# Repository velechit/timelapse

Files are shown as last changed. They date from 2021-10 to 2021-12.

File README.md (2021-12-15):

# Timelapse Timer

Photography Timer based on Atmega8 controller,  OLED display and button controls.

## Specialities:

* USB Based boot loader (based on [baerwolf](https://github.com/baerwolf/USBaspLoader)'s code)
* Minimalsitic SSD1306 driver
* SoftSwitch power on

This project contains Circuit Schematic, PCB Layout, bootloader (Customized), Main Application

This project demonstrates using linker scripts to place code bases at specific location and re-using them across different codes
* Bootloader also implements a minimalistic SSD1306 driver. As the bootloader space in ATMEGA8 is limited to 2k (start address `0x1800`), the driver is placed at `0x1600` which can be accessed through absolute addressing
* The application program (the actual timelapse code) makes use of this SSD1306 driver through absolute addressing
## Progress so far

- [x] Bootloader
- [x] SSD1306 Driver
- [x] Integrate SSD1306 Driver with bootloader, and display a USB icon when in boot load mode
- [x] Update Makefile for bootloader to generate liner script for display driver entry points to be accessed by application program
- [x] Design the PCB
- [x] Get PCB Fabricated
- [x] Framework for the application
- [ ] Main application program

<br/>

**UPDATE 1: Added power off code in bootloader**

**UPDATE 2: Initial dummy firmware implemented which is simple counter**

**UPDATE 3: got the fabricated PCB, assembled, and uploaded the bootloader & the dummy firmware... till now all working**

**UPDATE 4: Framework for main application ready**

<br/>

 _I thought of fabricating the board myself. Due to insufficient time, I have ordered from online fab. I had two options for shipment either too expencive and fast delivery or too slow with easy on pockets. I have chosen the latter, waiting for the board to arrive_

**IMPORTANT Update : I found a issue with the power on circuitory that the internal IO driver transistor is too leakey and is permanently turning on the PMOS power gate. Hence I have added additional NMOS (`2n7002`) to ground externally**

## Toolchain needed
The bootloader and firmware are developed using barebone `avr-gcc` and `avr-libc`

Install `avr-gcc` and `avr-libc`. Under Windows you may chose to use [WinAVR](http://winavr.sourceforge.net/).

Under linux (`Ubuntu` epsecially)
> `sudo apt install gcc-avr avr-libc`

You will also need gmake (generally part of the installation). If not, install using
> `sudo apt install make`

Compile using `make`

### Fuse Settings
The board is designed with external oscillator module. Hence the below fuse settings are used for `Atmega8`

```
lfuse: 1 1 0 0 0 0 0 0 = 0xC0
       | | | | | | | |
       | | | | | | | +- CKSEL0   - External Clock
       | | | | | | +--- CKSEL1
       | | | | | +----- CKSEL2
       | | | | +------- CKSEL3
       | | | +--------- SUT0     - Startup Time 0ms
       | | +----------- SUT1
       | +------------- BODEN    - Brown-out detection disabled
       +--------------- BODLEVEL - Brown-out detection level (N/A)

hfuse: 1 1 0 0 1 0 0 0 = 0xC8
       | | | | | | | |
       | | | | | | | +- BOOTRST  - Reset boots to boot loader
       | | | | | | +--- BOOTSZ0  - Boot section size 2k
       | | | | | +----- BOOTSZ1
       | | | | +------- EESAVE   - No EEPROM save on program
       | | | +--------- CKOPT    - Full Swing Clock
       | | +----------- SPIEN    - Serial programming enabled
       | +------------- WTDON    - Watchdog Timer disabled
       +--------------- RSTDISBL - Reset not disabled
```
Program the above fuses using:

> `avrdude -p atmega8 -P usb -c usbasp -U lfuse:w:0xC0:m -U hfuse:w:0xC8:m`

## Uploading the bootloader
The bootloader and the fuse settings have to be uploaded using any other method of loading (Using Arduino as ISP or USBAsp programmer). Once programmed, the controller can be soldered to the application board and the programmed bootloader be used to upload the main firmware.

## 3D models
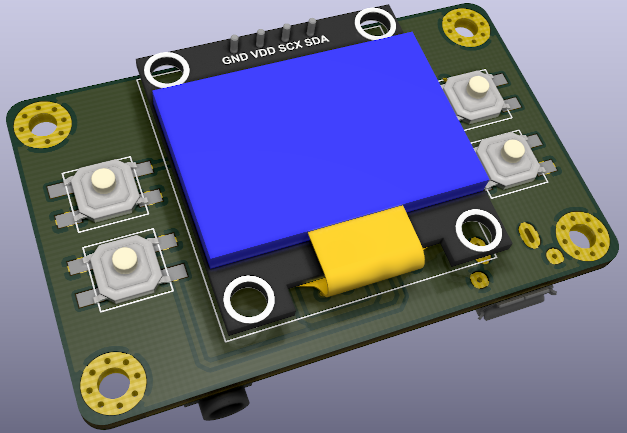
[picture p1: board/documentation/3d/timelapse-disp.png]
Board Side

<br/>
*3D Model of display side of the board*

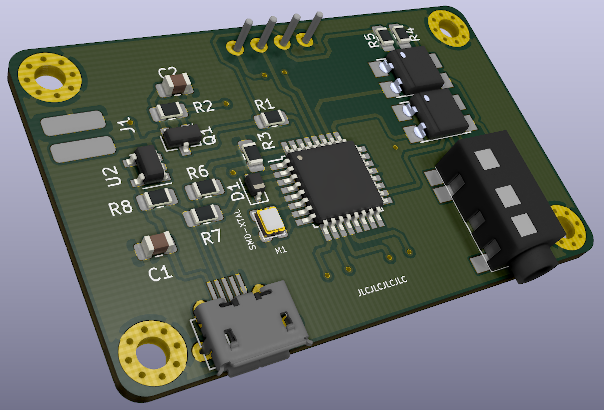
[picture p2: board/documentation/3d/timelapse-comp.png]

<br/>
*3D Model of component side of the board*

## Post Fabrication
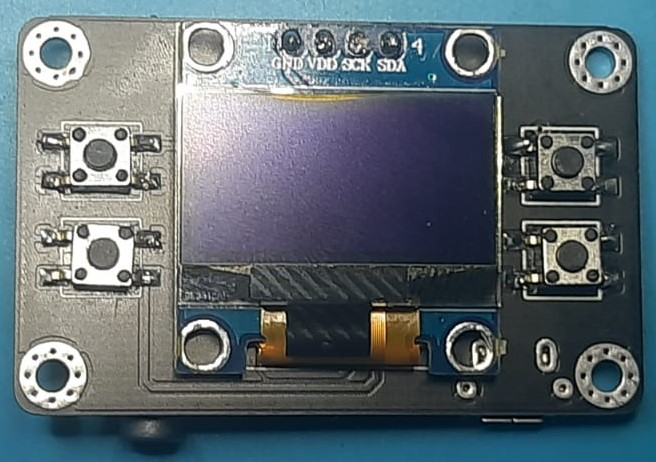
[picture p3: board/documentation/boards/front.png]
Board Side

<br/>
*Display side of the board*

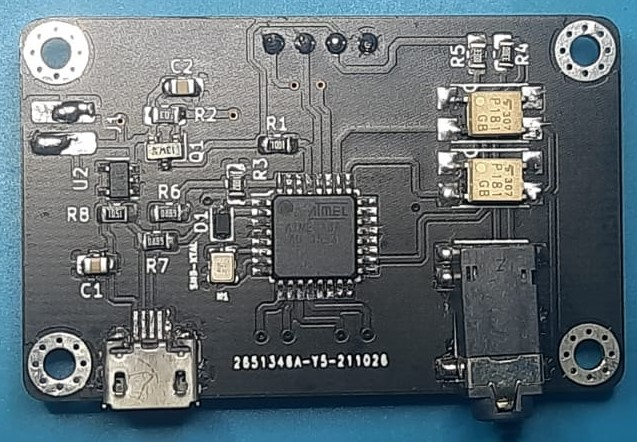
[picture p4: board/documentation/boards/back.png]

<br/>
*Component side of the board*

Full documentation can be found [here](https://raw.githack.com/velechit/timelapse/main/board/documentation/index.html)

PCB is designed using 

(https://www.kicad.org)

Download KiCad project files [here](board/timelapse.zip?raw=true)

Schematic can be found [here](board/schematic.pdf?raw=true)

email: elechi@gmail.com

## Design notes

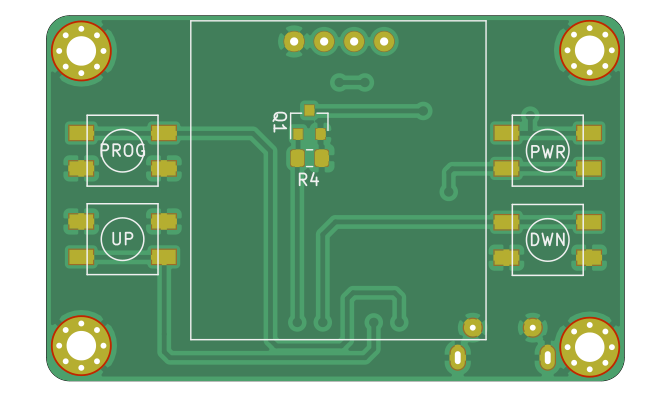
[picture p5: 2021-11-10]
board/documentation/boards/timelapse-back.png

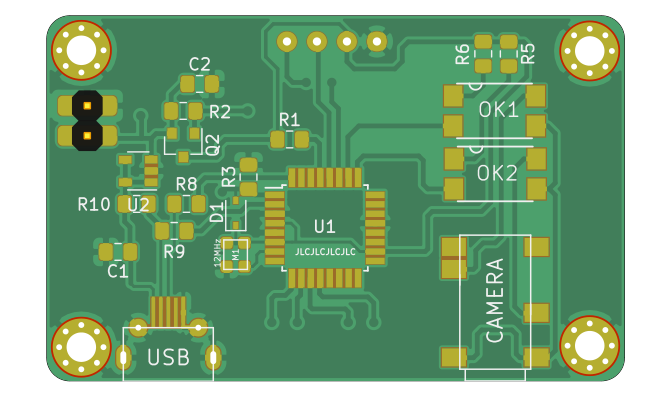
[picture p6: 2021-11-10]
board/documentation/boards/timelapse-front.png

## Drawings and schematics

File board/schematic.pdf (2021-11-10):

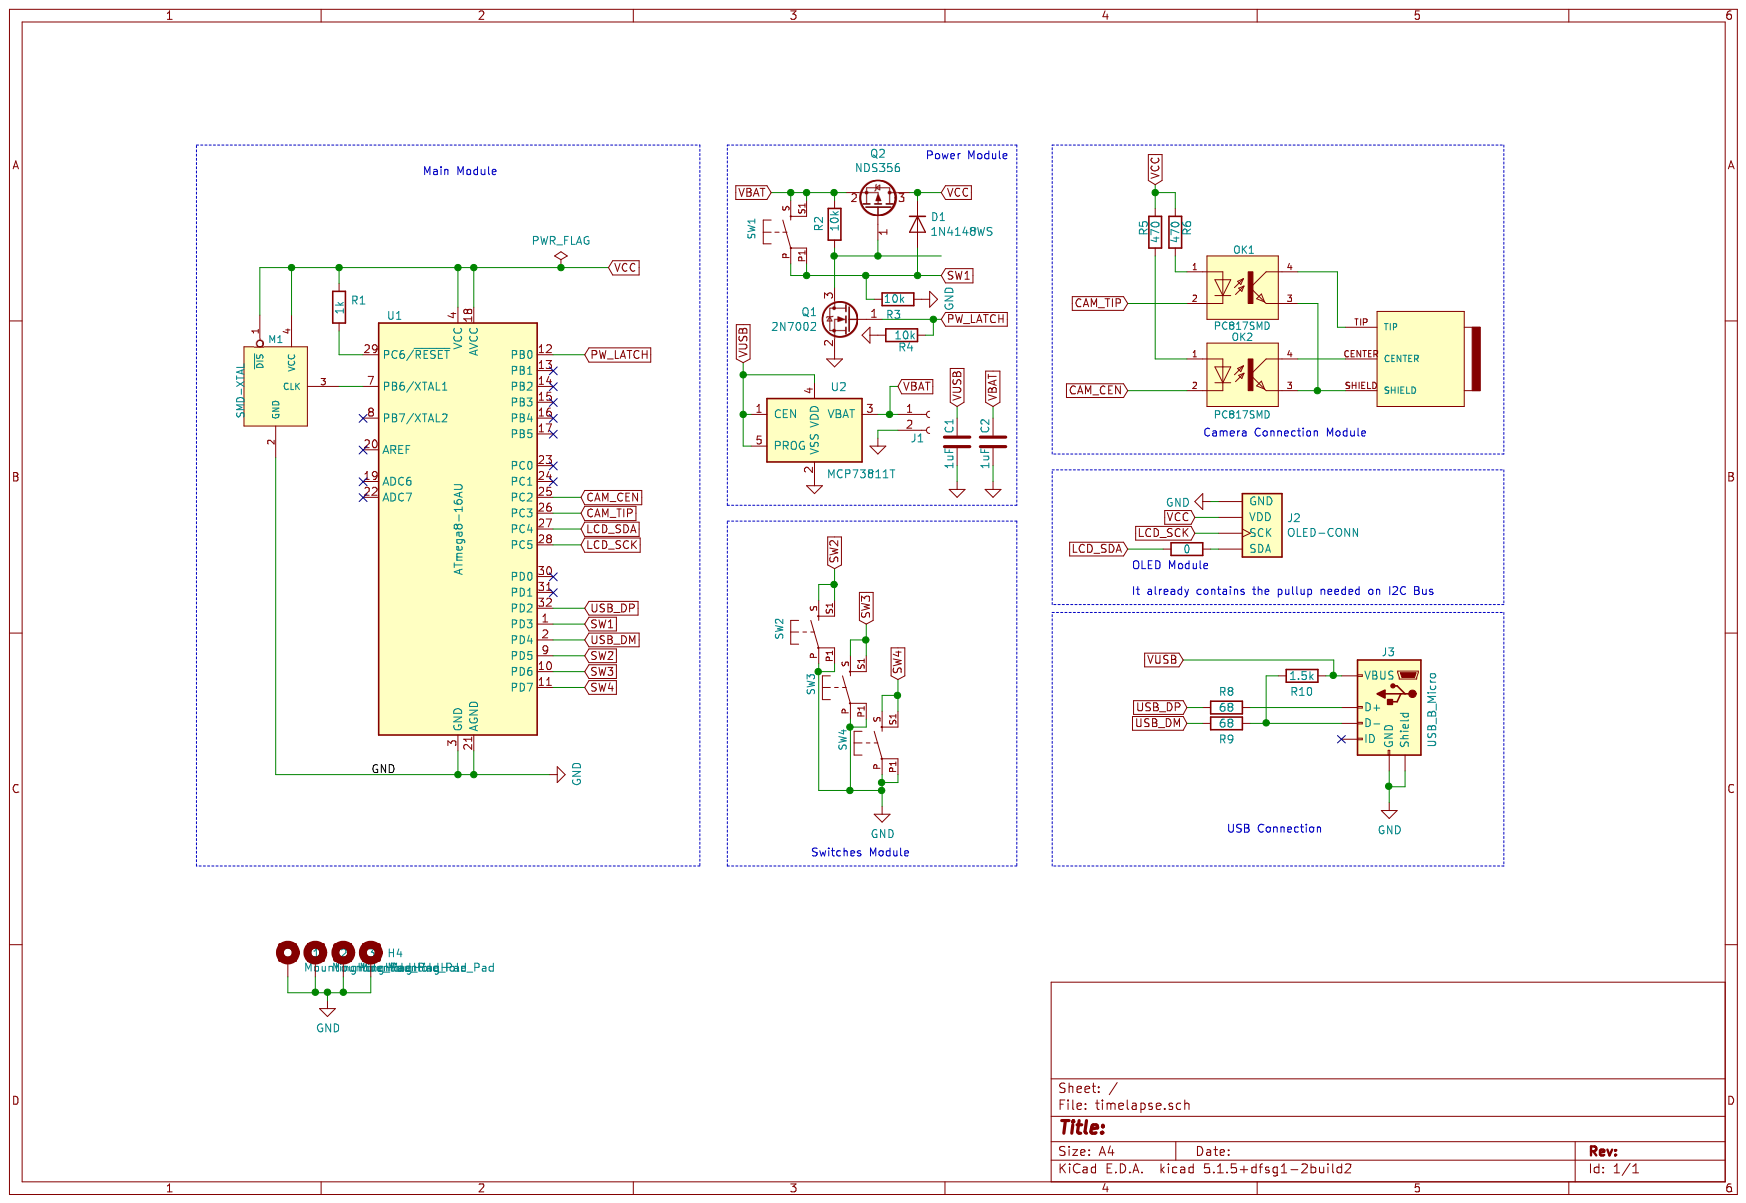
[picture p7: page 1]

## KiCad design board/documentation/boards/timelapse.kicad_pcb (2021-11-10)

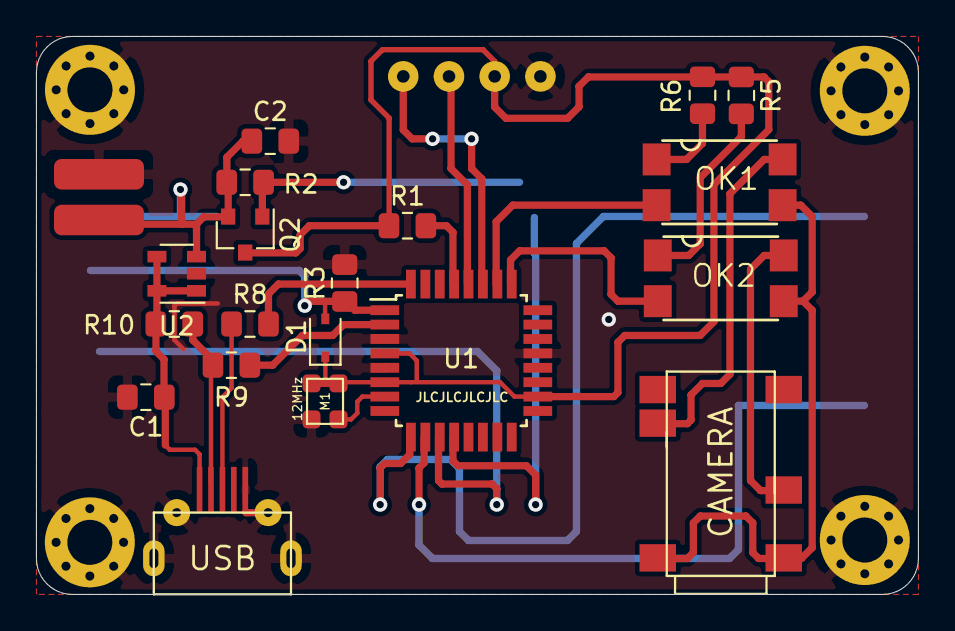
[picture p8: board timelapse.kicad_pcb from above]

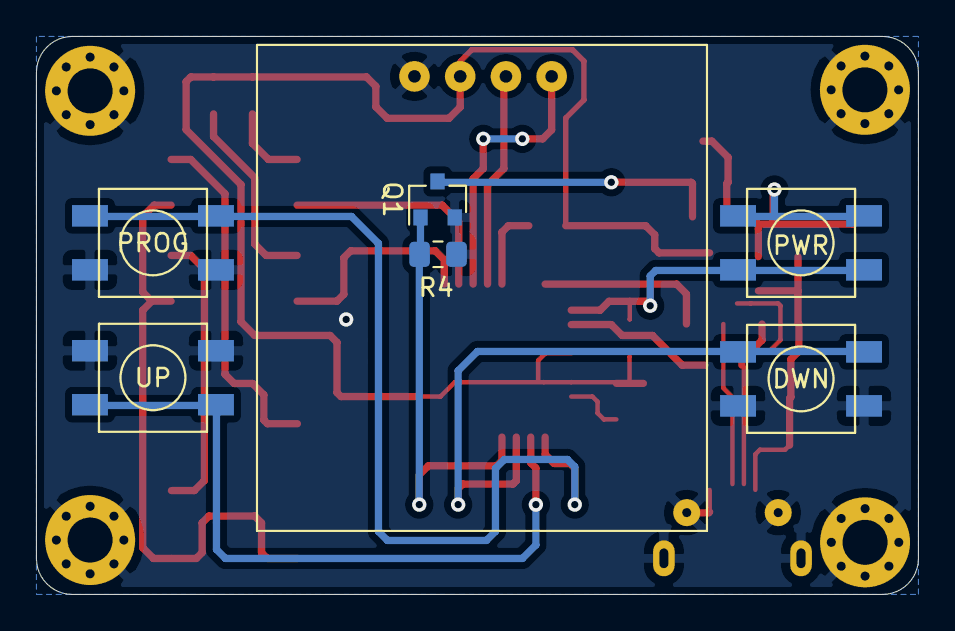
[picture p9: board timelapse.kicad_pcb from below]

Board: 2 copper layers, 49.0 x 31.0 mm, 31 parts (7 on the bottom side), 24 nets.

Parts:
C1, C2: 1uF; C_0805_2012Metric_Pad1.15x1.40mm_HandSolder
D1: 1N4148WS; D_SOD-323
H1, H2, H3, H4: MountingHole_Pad; MountingHole_2.5mm_Pad_Via
J1: Battery; PinHeader_1x02_P2.54mm_Vertical
J2: OLED-CONN; OLED-Display-0.96
J3: USB; MICROUSB-V8
M1: 12MHz; SMDXTAL
M2: CAMERA; CAM-CONN-NOKIA
OK1, OK2: PC817SMD; SMD4
Q1: 2N7002; SOT-23
Q2: NDS356; SOT-23
R1: 1k; R_0805_2012Metric_Pad1.15x1.40mm_HandSolder
R2, R3, R4: 10k; R_0805_2012Metric_Pad1.15x1.40mm_HandSolder
R5, R6: 470; R_0805_2012Metric_Pad1.15x1.40mm_HandSolder
R8, R9: 68; R_0805_2012Metric_Pad1.15x1.40mm_HandSolder
R10: 1.5k; R_0805_2012Metric_Pad1.15x1.40mm_HandSolder
SW1: PWR; 4PIN-S
SW2: PROG; 4PIN-S
SW3: UP; 4PIN-S
SW4: DWN; 4PIN-S
U1: ATmega8-16AU; TQFP-32_7x7mm_P0.8mm
U2: MCP73811T; SOT-23-5

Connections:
CAM_CEN: OK2.2, U1.25
CAM_TIP: OK1.2, U1.26
GND: C1.2, C2.2, H1.1, H2.1, H3.1, H4.1, J1.2, J2.1, J3.GND, J3.SHIELD, M1.2, Q1.2, R3.2, R4.2, SW2.P, SW2.P1, SW3.P, SW3.P1, SW4.P, SW4.P1, U1.3, U1.5, U1.21, U2.2
LCD_SCK: J2.3, U1.28
unnamed: J3.D+, R8.1
unnamed: J3.D-, R9.1, R10.2
unnamed: M1.3, U1.7
unnamed: M2.CENTER, OK2.4
unnamed: M2.SHIELD, OK1.3, OK2.3
unnamed: M2.TIP, OK1.4
unnamed: OK1.1, R6.2
unnamed: OK2.1, R5.2
unnamed: Q1.3, Q2.1, R2.2
unnamed: R1.2, U1.29
PW_LATCH: Q1.1, R4.1, U1.12
SW1: D1.2, R3.1, SW1.P, SW1.P1, U1.1
SW2: SW2.S, SW2.S1, U1.9
SW3: SW3.S, SW3.S1, U1.10
SW4: SW4.S, SW4.S1, U1.11
USB_DM: R9.2, U1.2
USB_DP: R8.2, U1.32
VBAT: C2.1, J1.1, Q2.2, R2.1, SW1.S, SW1.S1, U2.3
VCC: D1.1, J2.2, M1.1, M1.4, Q2.3, R1.1, R5.1, R6.1, U1.4, U1.6, U1.18
VUSB: C1.1, J3.VBUS, R10.1, U2.1, U2.4, U2.5

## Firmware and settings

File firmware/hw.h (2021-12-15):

#ifndef __HARDWARE_H__
#define __HARDWARE_H__

#define KEYPAD_DIR_PORT DDRD
#define KEYPAD_PORT     PIND
#define KEYPAD_PORT_OUT PORTD
#define KEYPAD_BTN1_BIT 3  // PWR
#define KEYPAD_BTN2_BIT 5  // PROG
#define KEYPAD_BTN3_BIT 6  // UP
#define KEYPAD_BTN4_BIT 7  // DOWN
#define KEYPAD_PWR_BIT  KEYPAD_BTN1_BIT

#define CAMERA_DIR_PORT   DDRC
#define CAMERA_PORT       PORTC
#define CAMERA_1_BIT      2
#define CAMERA_2_BIT      3

#define POWER_LATCH_DIR_PORT  DDRB
#define POWER_LATCH_PORT      PORTB
#define POWER_LATCH_BIT       0

#endif /* ! __HARDWARE_H__ */

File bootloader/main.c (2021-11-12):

/* Name: main.c
 * Project: USBaspLoader
 * Author: Christian Starkjohann
 * Author: Stephan Baerwolf
 * Creation Date: 2007-12-08
 * Modification Date: 2013-03-31
 * Tabsize: 4
 * Copyright: (c) 2007 by OBJECTIVE DEVELOPMENT Software GmbH
 * License: GNU GPL v2 (see License.txt)
 */

#include "spminterface.h"  /* must be included as first! */

#include <avr/io.h>
#include <avr/interrupt.h>
#include <avr/pgmspace.h>
#include <avr/wdt.h>
#include <avr/boot.h>
#include <avr/eeprom.h>
#include <util/delay.h>

#include "SSD1306.h"

#if 0
/*
 * 29.09.2012 /  30.09.2012
 * 
 * Since cpufunc.h is not needed in this context and
 * since it is not available in all toolchains, this include
 * becomes deactivated by github issue-report.
 * (In case of trouble it remains in sourcecode for reactivation.)
 * 
 * The autor would like to thank Lena-M for reporting this
 * issue (https://github.com/baerwolf/USBaspLoader/issues/1).
 */
#include <avr/cpufunc.h>
#endif

#include <avr/boot.h>

#include <string.h>



#include "bootloaderconfig.h"

#include "usbdrv/usbdrv.c"
static usbMsgLen_t usbFunctionDescriptor(struct usbRequest *rq) {
  return 0;
}

#ifndef BOOTLOADER_ADDRESS
  #error need to know the bootloaders flash address!
#endif
#define BOOTLOADER_PAGEADDR	(BOOTLOADER_ADDRESS - (BOOTLOADER_ADDRESS % SPM_PAGESIZE))

/* ------------------------------------------------------------------------ */

/* Request constants used by USBasp */
#define USBASP_FUNC_CONNECT         1
#define USBASP_FUNC_DISCONNECT      2
#define USBASP_FUNC_TRANSMIT        3
#define USBASP_FUNC_READFLASH       4
#define USBASP_FUNC_ENABLEPROG      5
#define USBASP_FUNC_WRITEFLASH      6
#define USBASP_FUNC_READEEPROM      7
#define USBASP_FUNC_WRITEEEPROM     8
#define USBASP_FUNC_SETLONGADDRESS  9

// additional USBasp Commands
#define USBASP_FUNC_SETISPSCK	     10
#define USBASP_FUNC_TPI_CONNECT      11
#define USBASP_FUNC_TPI_DISCONNECT   12
#define USBASP_FUNC_TPI_RAWREAD      13
#define USBASP_FUNC_TPI_RAWWRITE     14
#define USBASP_FUNC_TPI_READBLOCK    15
#define USBASP_FUNC_TPI_WRITEBLOCK   16
#define USBASP_FUNC_GETCAPABILITIES 127
/* ------------------------------------------------------------------------ */

#ifndef ulong
#   define ulong    unsigned long
#endif
#ifndef uint
#   define uint     unsigned int
#endif


/* allow compatibility with avrusbboot's bootloaderconfig.h: */
#ifdef BOOTLOADER_INIT
#   define bootLoaderInit()         BOOTLOADER_INIT
#   define bootLoaderExit()
#endif
#ifdef BOOTLOADER_CONDITION
#   define bootLoaderCondition()    BOOTLOADER_CONDITION
#endif

/* device compatibility: */
#ifndef GICR    /* ATMega*8 don't have GICR, use MCUCR instead */
#   define GICR     MCUCR
#endif

/* ------------------------------------------------------------------------ */

#if (FLASHEND) > 0xffff /* we need long addressing */
#   define CURRENT_ADDRESS  currentAddress.l
#   define addr_t           ulong
#else
#   define CURRENT_ADDRESS  currentAddress.w[0]
#   define addr_t           uint
#endif

typedef union longConverter{
    addr_t  l;
    uint    w[sizeof(addr_t)/2];
    uchar   b[sizeof(addr_t)];
}longConverter_t;


#define __IMPLEMENT_PRESERVE_WATCHDOG	((PRESERVE_WATCHDOG) && (!(USE_EXCESSIVE_ASSEMBLER)) && ((NEED_WATCHDOG) || (defined(__MCUCSR_COMPATMODE))))
#if (__IMPLEMENT_PRESERVE_WATCHDOG)
static uint8_t __original_WDTCR;
#endif

#if (BOOTLOADER_CAN_EXIT)
#	if (BOOTLOADER_LOOPCYCLES_TIMEOUT)
#		if (BOOTLOADER_LOOPCYCLES_TIMEOUT < 256)
#			if ((HAVE_UNPRECISEWAIT))
	 register uint8_t timeout_remaining __asm__("r2");
#			else
static volatile uint8_t timeout_remaining;
#			endif
#		else
static volatile uint16_t timeout_remaining;
#		endif
#	endif

#	define stayinloader_initialValue 0xfe
#	if ((HAVE_UNPRECISEWAIT))
/* here we have to assume we need to optimize for every byte */
	 register uint8_t stayinloader __asm__("r17");
#	else
static volatile uint8_t stayinloader;
#	endif
#endif

static longConverter_t  	currentAddress; /* in bytes */
static uchar            	bytesRemaining;
static uchar            	isLastPage;
#if HAVE_EEPROM_PAGED_ACCESS
static uchar            	currentRequest;
#else
static const uchar      	currentRequest = 0;
#endif

static const uchar  signatureBytes[4] = {
#ifdef SIGNATURE_BYTES
    SIGNATURE_BYTES
#elif defined (__AVR_ATmega8535__)
    0x1e, 0x93, 0x08, 0
#elif defined (__AVR_ATmega8__) || defined (__AVR_ATmega8A__) || defined (__AVR_ATmega8HVA__)
    0x1e, 0x93, 0x07, 0
#elif defined (__AVR_ATmega16__)
    0x1e, 0x94, 0x03, 0
#elif defined (__AVR_ATmega32__)
    0x1e, 0x95, 0x02, 0
#elif defined (__AVR_ATmega48__) || defined (__AVR_ATmega48A__)
    #error ATmega48 does not support bootloaders!
    0x1e, 0x92, 0x05, 0
#elif defined (__AVR_ATmega48PA__) || defined (__AVR_ATmega48P__)
    #error ATmega48P does not support bootloaders!
    0x1e, 0x92, 0x0A, 0
#elif defined (__AVR_ATmega88__) || defined (__AVR_ATmega88A__)
    0x1e, 0x93, 0x0a, 0
#elif defined (__AVR_ATmega88PA__) || defined (__AVR_ATmega88P__)
    0x1e, 0x93, 0x0F, 0
#elif defined (__AVR_ATmega162__)
    0x1e, 0x94, 0x04, 0
#elif defined (__AVR_ATmega164A__)
    0x1e, 0x94, 0x0f, 0
#elif defined (__AVR_ATmega164P__) || defined (__AVR_ATmega164PA__)
    0x1e, 0x94, 0x0a, 0
#elif defined (__AVR_ATmega168__) || defined (__AVR_ATmega168A__)
    0x1e, 0x94, 0x06, 0
#elif defined (__AVR_ATmega168PA__) || defined (__AVR_ATmega168P__)
    0x1e, 0x94, 0x0B, 0
#elif defined (__AVR_ATmega324A__)
    0x1e, 0x95, 0x15, 0
#elif defined (__AVR_ATmega324P__)
    0x1e, 0x95, 0x08, 0
#elif defined (__AVR_ATmega324PA__)
    0x1e, 0x95, 0x11, 0
#elif defined (__AVR_ATmega328__)
    0x1e, 0x95, 0x14, 0
#elif defined (__AVR_ATmega328P__)
    0x1e, 0x95, 0x0f, 0
#elif defined (__AVR_ATmega640__)
    0x1e, 0x96, 0x08, 0
#elif defined (__AVR_ATmega644__) || defined (__AVR_ATmega644A__)
    0x1e, 0x96, 0x09, 0
#elif defined (__AVR_ATmega644P__) || defined (__AVR_ATmega644PA__)
    0x1e, 0x96, 0x0a, 0
#elif defined (__AVR_ATmega128__)
    0x1e, 0x97, 0x02, 0
#elif defined (__AVR_ATmega1280__)
    0x1e, 0x97, 0x03, 0
#elif defined (__AVR_ATmega1281__)
    0x1e, 0x97, 0x04, 0
#elif defined (__AVR_ATmega1284__)
    0x1e, 0x97, 0x06, 0
#elif defined (__AVR_ATmega1284P__)
    0x1e, 0x97, 0x05, 0
#elif defined (__AVR_ATmega2560__)
    0x1e, 0x98, 0x01, 0
#elif defined (__AVR_ATmega2561__)
    0x1e, 0x98, 0x02, 0
#else
#   if (defined(SIGNATURE_0) && defined(SIGNATURE_1) && defined(SIGNATURE_2))
#     warning "Device signature is not known - using AVR Libc suggestion..."
    SIGNATURE_0, SIGNATURE_1, SIGNATURE_2, 0
#   else
#     error "Device signature is not known, please edit main.c!"
#   endif
#endif
};

/* ------------------------------------------------------------------------ */

#if (HAVE_BOOTLOADERENTRY_FROMSOFTWARE)
void __attribute__ ((section(".init3"),naked,used,no_instrument_function)) __BOOTLOADERENTRY_FROMSOFTWARE__bootup_investigate_RAMEND(void);
void __BOOTLOADERENTRY_FROMSOFTWARE__bootup_investigate_RAMEND(void) {
  asm volatile (
    "in		%[mcucsrval]	,	%[mcucsrio]\n\t"
    "ldi	r29		,	%[ramendhi]\n\t"
    "ldi	r28		,	%[ramendlo]\n\t"
#if (FLASHEND>131071)
    "ld		%[result]	,	Y+\n\t"
    "cpi	%[result]	,	%[bootaddrhi]\n\t"
    "brne	__BOOTLOADERENTRY_FROMSOFTWARE__bootup_investigate_RAMEND_mismatch%=\n\t"
#endif
    "ld		%[result]	,	Y+\n\t"
    "cpi	%[result]	,	%[bootaddrme]\n\t"
    "ld		%[result]	,	Y+\n\t"
    "breq	__BOOTLOADERENTRY_FROMSOFTWARE__bootup_investigate_RAMEND_done%=\n\t"

    "__BOOTLOADERENTRY_FROMSOFTWARE__bootup_investigate_RAMEND_mismatch%=:\n\t"
    "ldi	%[result]	,	0xff\n\t"

    "__BOOTLOADERENTRY_FROMSOFTWARE__bootup_investigate_RAMEND_done%=:\n\t"
    : [result]		"=a" (__BOOTLOADERENTRY_FROMSOFTWARE__bootup_RAMEND_doesmatch),
      [mcucsrval]	"=a" (__BOOTLOADERENTRY_FROMSOFTWARE__bootup_MCUCSR)
    : [mcucsrio]	"I"  (_SFR_IO_ADDR(MCUCSR)),
#if (FLASHEND>131071)
      [ramendhi]	"M" (((RAMEND - 2) >> 8) & 0xff),
      [ramendlo]	"M" (((RAMEND - 2) >> 0) & 0xff),
      [bootaddrhi]	"M" (((__BOOTLOADERENTRY_FROMSOFTWARE__EXPECTEDADDRESS) >>16) & 0xff),
#else
      [ramendhi]	"M" (((RAMEND - 1) >> 8) & 0xff),
      [ramendlo]	"M" (((RAMEND - 1) >> 0) & 0xff),
#endif
      [bootaddrme]	"M" (((__BOOTLOADERENTRY_FROMSOFTWARE__EXPECTEDADDRESS) >> 8) & 0xff)
    
  );
}
#endif

#if (USE_BOOTUP_CLEARRAM)
/*
* Under normal circumstances, RESET will not clear contents of RAM.
* As always, if you want it done - do it yourself...
*/
void __attribute__ ((section(".init3"),naked,used,no_instrument_function)) __func_clearram(void);
void __func_clearram(void) {
  extern size_t __bss_end;
  asm volatile (
    "__clearram:\n\t"
#if (!(HAVE_BOOTLOADERENTRY_FROMSOFTWARE))
    "ldi r29, %[ramendhi]\n\t"
    "ldi r28, %[ramendlo]\n\t"
#endif
    "__clearramloop%=:\n\t"
    "st -Y , __zero_reg__\n\t"
    "cp r28, %A[bssend]\n\t"
    "cpc r29, %B[bssend]\n\t"
    "brne __clearramloop%=\n\t"
    :
    : [ramendhi] "M" (((RAMEND+1)>>8) & 0xff),
      [ramendlo] "M" (((RAMEND+1)>>0) & 0xff),
      [bssend] "r" (&__bss_end)
    : "memory"
      );
}
#endif

#if (!USE_EXCESSIVE_ASSEMBLER) || (!(defined (__AVR_ATmega8__) || defined (__AVR_ATmega8A__) || defined (__AVR_ATmega8HVA__)))
static void (*nullVector)(void) __attribute__((__noreturn__));
#endif

#if (USE_EXCESSIVE_ASSEMBLER) && (defined (__AVR_ATmega8__) || defined (__AVR_ATmega8A__) || defined (__AVR_ATmega8HVA__))
static void __attribute__((naked,__noreturn__)) leaveBootloader(void);
static void leaveBootloader(void) {
  asm  volatile  (
  "cli\n\t"
  "sbi		%[usbddr],	%[usbminus]\n\t"  
  "cbi		%[port],	%[bit]\n\t"
  "out		%[usbintrenab],	__zero_reg__\n\t"
  "out		%[usbintrcfg],	__zero_reg__\n\t"
  "ldi		r31,		%[ivce]\n\t"
  "out		%[mygicr],	r31\n\t"
  "out		%[mygicr],	__zero_reg__\n\t"  
  "rjmp		nullVector\n\t"
  :
  : [port]        "I" (_SFR_IO_ADDR(PIN_PORT(JUMPER_PORT))),
    [bit]         "I" (PIN(JUMPER_PORT, JUMPER_BIT)),
    [usbintrenab] "I" (_SFR_IO_ADDR(USB_INTR_ENABLE)),
    [usbintrcfg]  "I" (_SFR_IO_ADDR(USB_INTR_CFG)),
    [usbddr]      "I" (_SFR_IO_ADDR(USBDDR)),
    [usbminus]    "I" (USBMINUS),
    [mygicr]      "I" (_SFR_IO_ADDR(GICR)),	      
    [ivce]        "I" (1<<IVCE)
);
  SSD1306_Clear();
}
#else
static void __attribute__((__noreturn__)) leaveBootloader(void);
static void leaveBootloader(void) {
    DBG1(0x01, 0, 0);
    cli();
    usbDeviceDisconnect();
    bootLoaderExit();
    USB_INTR_ENABLE = 0;
    USB_INTR_CFG = 0;       /* also reset config bits */
    GICR = (1 << IVCE);     /* enable change of interrupt vectors */
    GICR = (0 << IVSEL);    /* move interrupts to application flash section */

/* restore the original watchdog timer if necessary */
#if (__IMPLEMENT_PRESERVE_WATCHDOG)
    if (__original_WDTCR & _BV(WDE)) {
      __original_WDTCR &= ~(_BV(WDCE));
      wdt_reset();
      WDTCR |= (_BV(WDCE)) | (_BV(WDE));
      WDTCR  = __original_WDTCR;
      wdt_reset();
    }
#endif
/*
 * There seems to be another funny compiler Bug.
 * When gcc is using "eicall" opcode it forgets to modify EIND.
 * On devices with large flash memory there are some target address bits
 * missing. In this case some zero bits...
 */
#if (defined(EIND) && ((FLASHEND)>131071))
  EIND=0;
#endif
/* We must go through a global function pointer variable instead of writing
 *  ((void (*)(void))0)();
 * because the compiler optimizes a constant 0 to "rcall 0" which is not
 * handled correctly by the assembler.
 */
    nullVector();
}
#endif

/* ------------------------------------------------------------------------ */


uchar usbFunctionSetup_USBASP_FUNC_TRANSMIT(usbRequest_t *rq) {
  uchar rval = 0;
  usbWord_t address;
  address.bytes[1] = rq->wValue.bytes[1];
  address.bytes[0] = rq->wIndex.bytes[0];

  if(rq->wValue.bytes[0] == 0x30){        /* read signature */
    rval = rq->wIndex.bytes[0] & 3;
    rval = signatureBytes[rval];
#if HAVE_READ_LOCK_FUSE
#if defined (__AVR_ATmega8535__) || 					\
    defined (__AVR_ATmega8__) || defined (__AVR_ATmega8A__) || 		\
    defined (__AVR_ATmega16__) || defined (__AVR_ATmega32__)
  }else if(rq->wValue.bytes[0] == 0x58 && rq->wValue.bytes[1] == 0x00){  /* read lock bits */
      rval = boot_lock_fuse_bits_get(GET_LOCK_BITS);
  }else if(rq->wValue.bytes[0] == 0x50 && rq->wValue.bytes[1] == 0x00){  /* read lfuse bits */
      rval = boot_lock_fuse_bits_get(GET_LOW_FUSE_BITS);
  }else if(rq->wValue.bytes[0] == 0x58 && rq->wValue.bytes[1] == 0x08){  /* read hfuse bits */
      rval = boot_lock_fuse_bits_get(GET_HIGH_FUSE_BITS);

#elif defined (__AVR_ATmega48__)   || defined (__AVR_ATmega48A__)   || defined (__AVR_ATmega48P__)   || defined (__AVR_ATmega48PA__)  ||  \
defined (__AVR_ATmega88__)   || defined (__AVR_ATmega88A__)   || defined (__AVR_ATmega88P__)   || defined (__AVR_ATmega88PA__)  ||  \
defined (__AVR_ATmega162__)  || 												      \
defined (__AVR_ATmega164A__) || defined (__AVR_ATmega164P__)  || 								      \
defined (__AVR_ATmega168__)  || defined (__AVR_ATmega168A__)  || defined (__AVR_ATmega168P__)  || defined (__AVR_ATmega168PA__) ||  \
defined (__AVR_ATmega324A__) || defined (__AVR_ATmega324P__)  ||								      \
defined (__AVR_ATmega328__)  || defined (__AVR_ATmega328P__)  ||								      \
defined (__AVR_ATmega640__)  ||													\
defined (__AVR_ATmega644__)  || defined (__AVR_ATmega644A__)  || defined (__AVR_ATmega644P__) || defined (__AVR_ATmega644PA__)  ||  \
defined (__AVR_ATmega128__)  ||													      \
defined (__AVR_ATmega1280__) ||													\
defined (__AVR_ATmega1281__) ||													\
defined (__AVR_ATmega1284__) || defined (__AVR_ATmega1284P__)  ||													\
defined (__AVR_ATmega2560__) ||													\
defined (__AVR_ATmega2561__)
  }else if(rq->wValue.bytes[0] == 0x58 && rq->wValue.bytes[1] == 0x00){  /* read lock bits */
      rval = boot_lock_fuse_bits_get(GET_LOCK_BITS);
  }else if(rq->wValue.bytes[0] == 0x50 && rq->wValue.bytes[1] == 0x00){  /* read lfuse bits */
      rval = boot_lock_fuse_bits_get(GET_LOW_FUSE_BITS);
  }else if(rq->wValue.bytes[0] == 0x58 && rq->wValue.bytes[1] == 0x08){  /* read hfuse bits */
      rval = boot_lock_fuse_bits_get(GET_HIGH_FUSE_BITS);
  }else if(rq->wValue.bytes[0] == 0x50 && rq->wValue.bytes[1] == 0x08){  /* read efuse bits */
      rval = boot_lock_fuse_bits_get(GET_EXTENDED_FUSE_BITS );
#else
  #warning "HAVE_READ_LOCK_FUSE is activated but MCU unknown -> will not support this feature"
#endif
#endif
#if HAVE_FLASH_BYTE_READACCESS
  }else if(rq->wValue.bytes[0] == 0x20){  /* read FLASH low  byte */
#if ((FLASHEND) > 65535)
      rval = pgm_read_byte_far((((addr_t)address.word)<<1)+0);
#else
      rval = pgm_read_byte((((addr_t)address.word)<<1)+0);
#endif
  }else if(rq->wValue.bytes[0] == 0x28){  /* read FLASH high byte */
#if ((FLASHEND) > 65535)
      rval = pgm_read_byte_far((((addr_t)address.word)<<1)+1);
#else
      rval = pgm_read_byte((((addr_t)address.word)<<1)+1);
#endif
#endif
#if HAVE_EEPROM_BYTE_ACCESS
  }else if(rq->wValue.bytes[0] == 0xa0){  /* read EEPROM byte */
      rval = eeprom_read_byte((void *)address.word);
  }else if(rq->wValue.bytes[0] == 0xc0){  /* write EEPROM byte */
      eeprom_write_byte((void *)address.word, rq->wIndex.bytes[1]);
#endif
#if HAVE_CHIP_ERASE
  }else if(rq->wValue.bytes[0] == 0xac && rq->wValue.bytes[1] == 0x80){  /* chip erase */
      addr_t addr;
#if HAVE_BLB11_SOFTW_LOCKBIT
      for(addr = 0; addr < (addr_t)(BOOTLOADER_PAGEADDR) ; addr += SPM_PAGESIZE) {
#else
      for(addr = 0; addr <= (addr_t)(FLASHEND) ; addr += SPM_PAGESIZE) {
#endif
	  /* wait and erase page */
	  DBG1(0x33, 0, 0);
#   ifndef NO_FLASH_WRITE
	  boot_spm_busy_wait();
	  cli();
	  boot_page_erase(addr);
	  sei();
#   endif
      }
#endif
#if ((HAVE_BOOTLOADER_HIDDENEXITCOMMAND) && (BOOTLOADER_CAN_EXIT))
#	if ((HAVE_BOOTLOADER_HIDDENEXITCOMMAND != 0xac) && \
	    (HAVE_BOOTLOADER_HIDDENEXITCOMMAND != 0x20) && (HAVE_BOOTLOADER_HIDDENEXITCOMMAND != 0x28) && \
	    (HAVE_BOOTLOADER_HIDDENEXITCOMMAND != 0x40) && (HAVE_BOOTLOADER_HIDDENEXITCOMMAND != 0x48) && \
	    (HAVE_BOOTLOADER_HIDDENEXITCOMMAND != 0x4c) && \
	    (HAVE_BOOTLOADER_HIDDENEXITCOMMAND != 0xa0) && \
	    (HAVE_BOOTLOADER_HIDDENEXITCOMMAND != 0xc0) && \
	    (HAVE_BOOTLOADER_HIDDENEXITCOMMAND != 0x58) && \
	    (HAVE_BOOTLOADER_HIDDENEXITCOMMAND != 0x5c) && \
	    (HAVE_BOOTLOADER_HIDDENEXITCOMMAND != 0x30) && \
	    (HAVE_BOOTLOADER_HIDDENEXITCOMMAND != 0xac) && \
	    (HAVE_BOOTLOADER_HIDDENEXITCOMMAND != 0x50) && (HAVE_BOOTLOADER_HIDDENEXITCOMMAND != 0x58) && \
	    (HAVE_BOOTLOADER_HIDDENEXITCOMMAND != 0x38))
  }else if(rq->wValue.bytes[0] == (HAVE_BOOTLOADER_HIDDENEXITCOMMAND)){  /* cause a bootLoaderExit at disconnect */
      stayinloader = 0xf1;  /* we need to be connected - so assume it */
#	endif
#endif
  }else{
      /* ignore all others, return default value == 0 */
  }
        
  return rval;
}


usbMsgLen_t usbFunctionSetup(uchar data[8])
{
usbRequest_t    *rq = (void *)data;
usbMsgLen_t     len = 0;
static uchar    replyBuffer[4];

    usbMsgPtr = (usbMsgPtr_t)replyBuffer;
    if(rq->bRequest == USBASP_FUNC_TRANSMIT){   /* emulate parts of ISP protocol */
        replyBuffer[3] = usbFunctionSetup_USBASP_FUNC_TRANSMIT(rq);
        len = (usbMsgLen_t)4;
    }else if((rq->bRequest == USBASP_FUNC_ENABLEPROG) || (rq->bRequest == USBASP_FUNC_SETISPSCK)){
        /* replyBuffer[0] = 0; is never touched and thus always 0 which means success */
        len = (usbMsgLen_t)1;
    }else if(rq->bRequest >= USBASP_FUNC_READFLASH && rq->bRequest <= USBASP_FUNC_SETLONGADDRESS){
        currentAddress.w[0] = rq->wValue.word;
        if(rq->bRequest == USBASP_FUNC_SETLONGADDRESS){
#if (FLASHEND) > 0xffff
            currentAddress.w[1] = rq->wIndex.word;
#endif
        }else{
            bytesRemaining = rq->wLength.bytes[0];
            /* if(rq->bRequest == USBASP_FUNC_WRITEFLASH) only evaluated during writeFlash anyway */
            isLastPage = rq->wIndex.bytes[1] & 0x02;
#if HAVE_EEPROM_PAGED_ACCESS
            currentRequest = rq->bRequest;
#endif
            len = USB_NO_MSG; /* hand over to usbFunctionRead() / usbFunctionWrite() */
        }

    }else if(rq->bRequest == USBASP_FUNC_DISCONNECT){

#if BOOTLOADER_CAN_EXIT
#	ifdef CONFIG_HAVE__BOOTLOADER_ABORTTIMEOUTONACT
      /* let the main loop know for ever that here was activity */
      stayinloader	   &= (0xfc);
#	else
      stayinloader	   &= (0xfe);
#	endif
#endif
    }else{
        /* ignore: others, but could be USBASP_FUNC_CONNECT */
#if BOOTLOADER_CAN_EXIT
	stayinloader	   |= (0x01);
#endif
    }
    return len;
}

#if (USE_EXCESSIVE_ASSEMBLER) && ((!HAVE_CHIP_ERASE) || (HAVE_ONDEMAND_PAGEERASE)) && (SPM_PAGESIZE <= 256) && (((BOOTLOADER_PAGEADDR>>0)&0xff) == 0)
uchar usbFunctionWrite(uchar *data, uchar len)
{
uchar   isLast;

    DBG1(0x31, (void *)&currentAddress.l, 4);
    if(len > bytesRemaining)
        len = bytesRemaining;
    bytesRemaining -= len;
    isLast = bytesRemaining == 0;
    if(currentRequest >= USBASP_FUNC_READEEPROM){
        uchar i;
        for(i = 0; i < len; i++){
            eeprom_write_byte((void *)(currentAddress.w[0]++), *data++);
        }
    }else{
	asm  volatile  (
	  "sbrc		%[len], 0\n\t"
	  "inc		%[len]\n\t"
"usbFunctionWrite_flashloop:\n\t"
	  "subi		%[len], 2\n\t"
	  "brlo		usbFunctionWrite_finished\n\t"
	  
#if HAVE_BLB11_SOFTW_LOCKBIT
	  "cpi		r31, %[blsaddrhi]\n\t"			/* accelerated BLB11_SOFTW_LOCKBIT check */
	  "brsh		usbFunctionWrite_finished\n\t"
// 	  "brlo		usbFunctionWrite_addrunlock_ok\n\t"
// 	  "brne		usbFunctionWrite_finished\n\t"
// 	  "cpi		r30, %[blsaddrlo]\n\t"
// 	  "brlo		usbFunctionWrite_addrunlock_ok\n\t"
// 	  "rjmp		usbFunctionWrite_finished\n\t"
// "usbFunctionWrite_addrunlock_ok:\n\t"
#endif
	  "rcall	usbFunctionWrite_waitA\n\t"
	  "cli\n\t"						/* r0 or r1 may be __zero_reg__ and may become dangerous nonzero within interrupts */
	  "ld		r0,		X+\n\t"
	  "ld		r1,		X+\n\t"

	  "ldi		r18,		%[pagfillval]\n\t"
	  "rcall	usbFunctionWrite_saveflash\n\t"	/* page fill */

	  "mov		r18,		r30\n\t"
	  "subi		r18,		0xfe\n\t"		/* add with 2 */
	  "andi		r18,		%[pagemask]\n\t"
	  "breq		usbFunctionWrite_pageisfull\n\t"
	  "tst		%[islast]\n\t"
	  "breq		usbFunctionWrite_skippageisfull\n\t"
	  "tst		%[isLastPage]\n\t"
	  "breq		usbFunctionWrite_skippageisfull\n\t"
	  "cpi		%[len],		0\n\t"
	  "brne		usbFunctionWrite_skippageisfull\n\t"

"usbFunctionWrite_pageisfull:\n\t"				/* start writing the page */
	  "ldi		r18,		%[pageraseval]\n\t"
	  "rcall	usbFunctionWrite_saveflash\n\t"	/* page erase */
	  "rcall	usbFunctionWrite_waitA\n\t"

	  "ldi		r18,		%[pagwriteval]\n\t"
	  "rcall	usbFunctionWrite_saveflash\n\t"	/* page write */
	  "rcall	usbFunctionWrite_waitA\n\t"

	  "in		__tmp_reg__,	%[spmcr]\n\t"
	  "sbrs		__tmp_reg__,	%[rwwsbbit]\n\t"
	  "rjmp		usbFunctionWrite_skippageisfull\n\t"
	  "ldi		r18,		%[rwwenrval]\n\t"
	  "rcall	usbFunctionWrite_saveflash\n\t"	/* reenable rww*/
// 	  "rcall	usbFunctionWrite_waitA\n\t"


"usbFunctionWrite_skippageisfull:\n\t"	  
	  "adiw		r30,		0x2\n\t"
	  "rjmp		usbFunctionWrite_flashloop\n\t"

"usbFunctionWrite_saveflash:\n\t"
	  "cli\n\t"
	  "out		%[spmcr],	r18\n\t"
	  "spm\n\t"
	  "clr		__zero_reg__\n\t"			/* if r0 or r1 is __zero_reg__ it may have become inconsisten while page-fill */
	  "sei\n\t"
	  "ret\n\t"

"usbFunctionWrite_waitA:\n\t"
	  "in		__tmp_reg__,	%[spmcr]\n\t"
	  "sbrc		__tmp_reg__,	%[spmenbit]\n\t"
	  "rjmp		usbFunctionWrite_waitA\n\t"
	  "ret\n\t"
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

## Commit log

2021-10-28 Adding Board Data
    [timelapse.kicad_pcb]
2021-11-10 Fixed schematic and board for power control circuit
    Power Circuit had problem of leaky IO driver nmos within the controller
    added external nmos (2n7002) to take care of proper power on
    [timelapse.kicad_pcb]
2021-11-12 Added code in bootloader for power-off
    Power off is added to bootloader based on Timer0
2021-11-24 Post Fabrication & Assembly
2021-12-15 Initial Framework of the application firmware
    TODO: Still camera control driver to be written
2021-12-15 Adding Camera framework
